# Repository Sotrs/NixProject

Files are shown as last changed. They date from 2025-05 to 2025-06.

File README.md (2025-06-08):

# NixProject By Sotiris Zannetos Readme Work In Progress
Nixe Clock Project Including Electronics, Software and 3d Designing for Enclosure

By looking at the Nixie Datasheet we know that each tube requires 10 different Inputs to turn each digit on (Will not be using the commas). For this clock I will be using the classic IN-14 Tube.


My MCU of choice is the ATmega328P which is a very popular choice that is also used in Arduino devices, it has a very well established documentation and support and can also be programmed using the Arduino IDE. This is exactly what I need as the Arduino IDE by itself is simple and easy to use and is also very well documented and supported by its community.




Now in order to turn on the tubes we need a driver that can take the digital output of the ATmega and turn on the particular digit we want to light up. We have a few problems we must solve in order to achieve that:
1. The clock we want to create will be a Six-Digit clock "HH:MM:SS" meaning we need 60 individual outputs. Unfortunately the Atmega328P can maxes out at '18', including the analog outputs as digital I/O's.
2. The tubes require a whopping 170V DC in order to light up and about 145V DC to keep running. That is not something we can control using only the digital outputs of a 5V DC Microcontroller.

To solve the first problem we can simply use dedicated Drivers, in fact a BCD-TO-DECIMAL Decoder was made specifically for driving Nixie Tubes known as the **SN74141** or its Soviet Sibling the **K155ID1**. This automatically solves the second problem as well as these drivers were created to handle the high voltage. The use of such drivers makes our project very simple as we can use 1 driver for each tube which brings us down from 60 individual outputs to 24 with each driver requiring 4 bits of info to control the 10 digits.



However, the problem is yet to be solved as 24 outputs are still more than what our MCU can give, we can tackle this problem using an I/O Expander with a Serial Interface. Utilizing THE I^2C Interface of the ATmega we can use I/O Expanders such as the **MCP23017** that will give us 16 extra I/O which are now more than enough of what we need. With that we can sucessfuly drive our nixie tubes using the MCU's Outputs!



We are still missing two critical components in our clock, while the ATmega328P can use its Internal 8MHz crystal Oscillator or an external 16MHz one they are still not very good at time keeping as this is not their intended use, also it will be unable to keep time while it is not powered. This is why we will use an RTC which is a device made for timekeeping. My choice of RTC is the **DS3231** with a simple I2C connection and a cr2032 battery it can keep time with an insane 2PPM accuracy.



Last but definetely not least we will need a DC-DC boost converter, the clock will be powered by 5V DC so we will need to take that 5V and convert it to 170V DC for our tubes. An easy solution to this is to use a premade module made by OMNIXIE called the **NCH8200HV**. It is small, efficient and widely used by many nixie clock creators, it simply does its job. It is the only premade module used in this project, dont't worry it will be embedded in our PCB very neatly and discreetly along with the other components.



Now, we have all of our components:
1. MCU -> ATmega 328p-AU
2. Tubes -> IN-14 Gazotron
3. RTC -> DS3231
4. I/O Expander -> MCP 23017  
5. DC-DC Converter -> NCH8200HV
6. SN74141 Drivers -> SN74141/K155ID1

We are ready to start the Electronic architecture, I will be using KiCad to create the schematics and PCB design, an open source and intuitive Electronic design software. Two push buttons will be used to control and set the time by the user. Also in order to program the arduino using the type C interface we will need an external USB to Serial device or in this case we will integrade an FTDI chip directily into our board using the very popular FT232RL.  



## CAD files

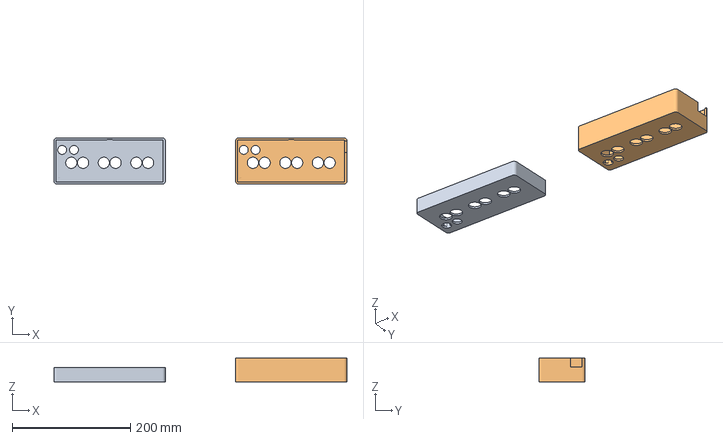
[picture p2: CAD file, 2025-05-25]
Hardware/3d Enclosure/NixieBaseRefined 3d Prinitng.3mf
495.7 x 78.5 x 40.0 mm
Nixie Case higher w holes version v6.step
ABOMINATUS Nixie.step

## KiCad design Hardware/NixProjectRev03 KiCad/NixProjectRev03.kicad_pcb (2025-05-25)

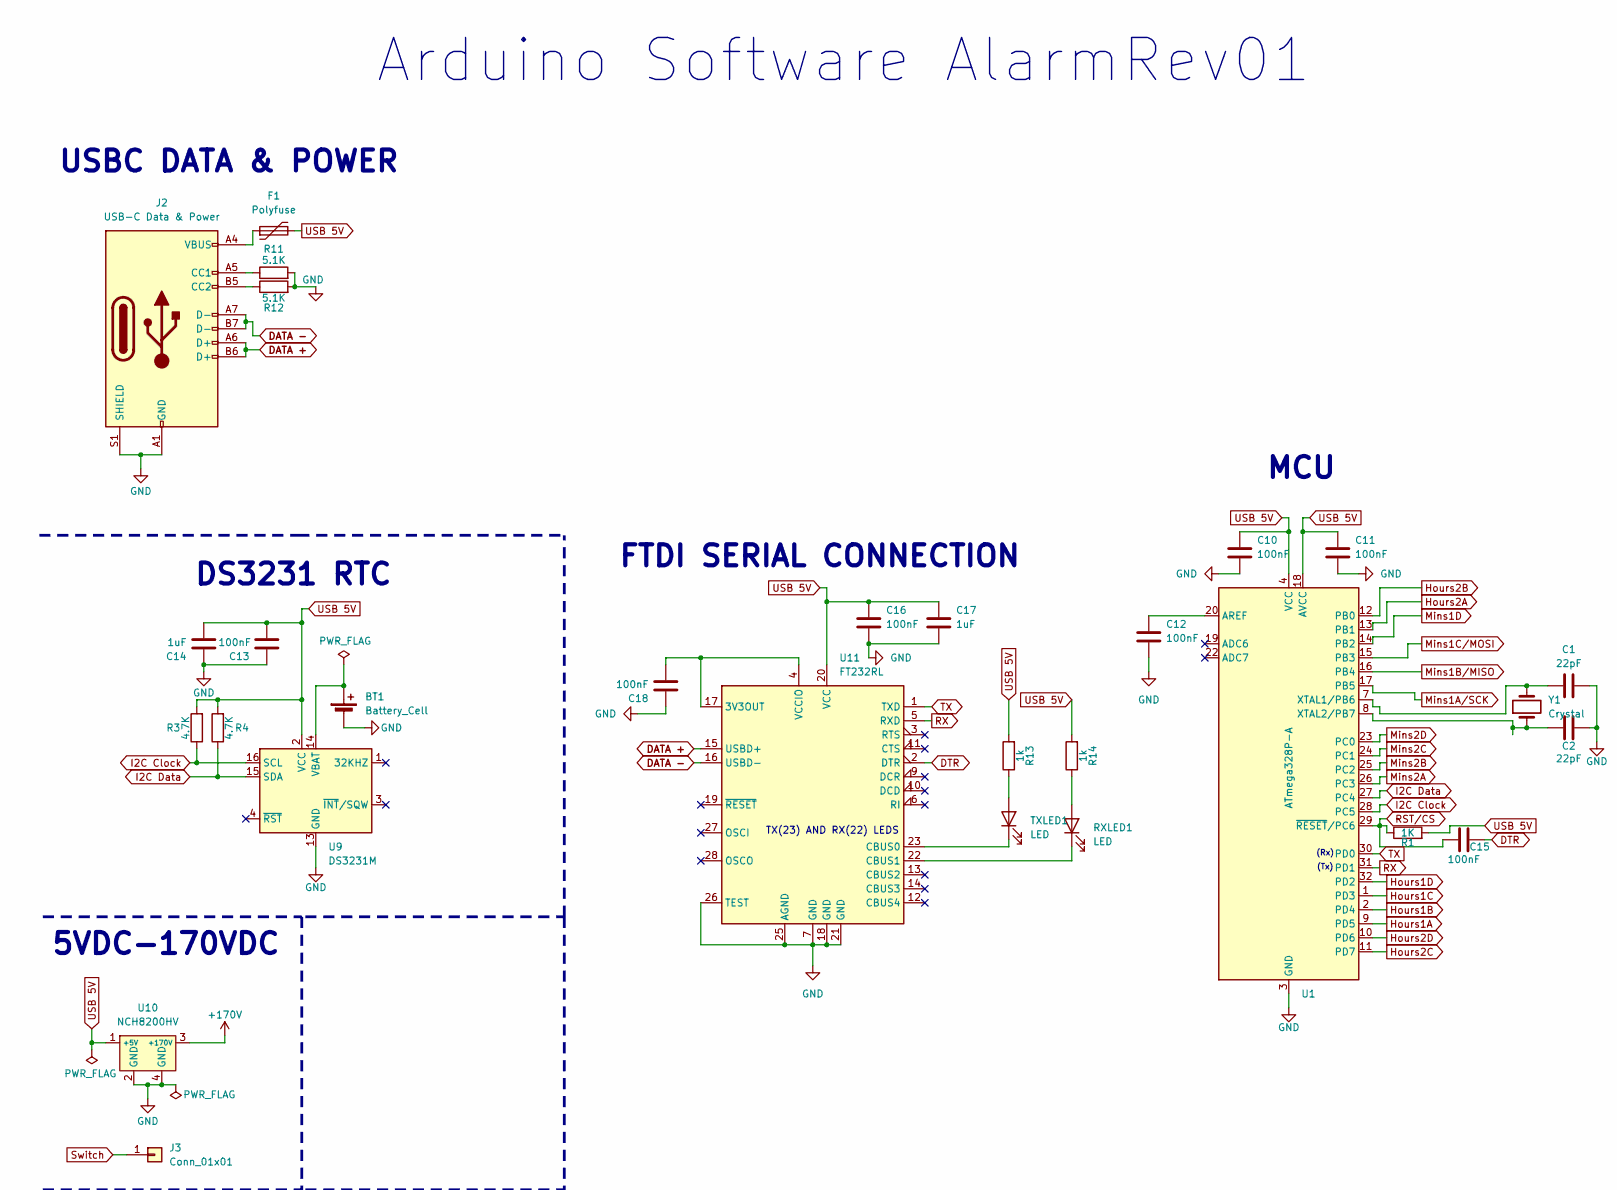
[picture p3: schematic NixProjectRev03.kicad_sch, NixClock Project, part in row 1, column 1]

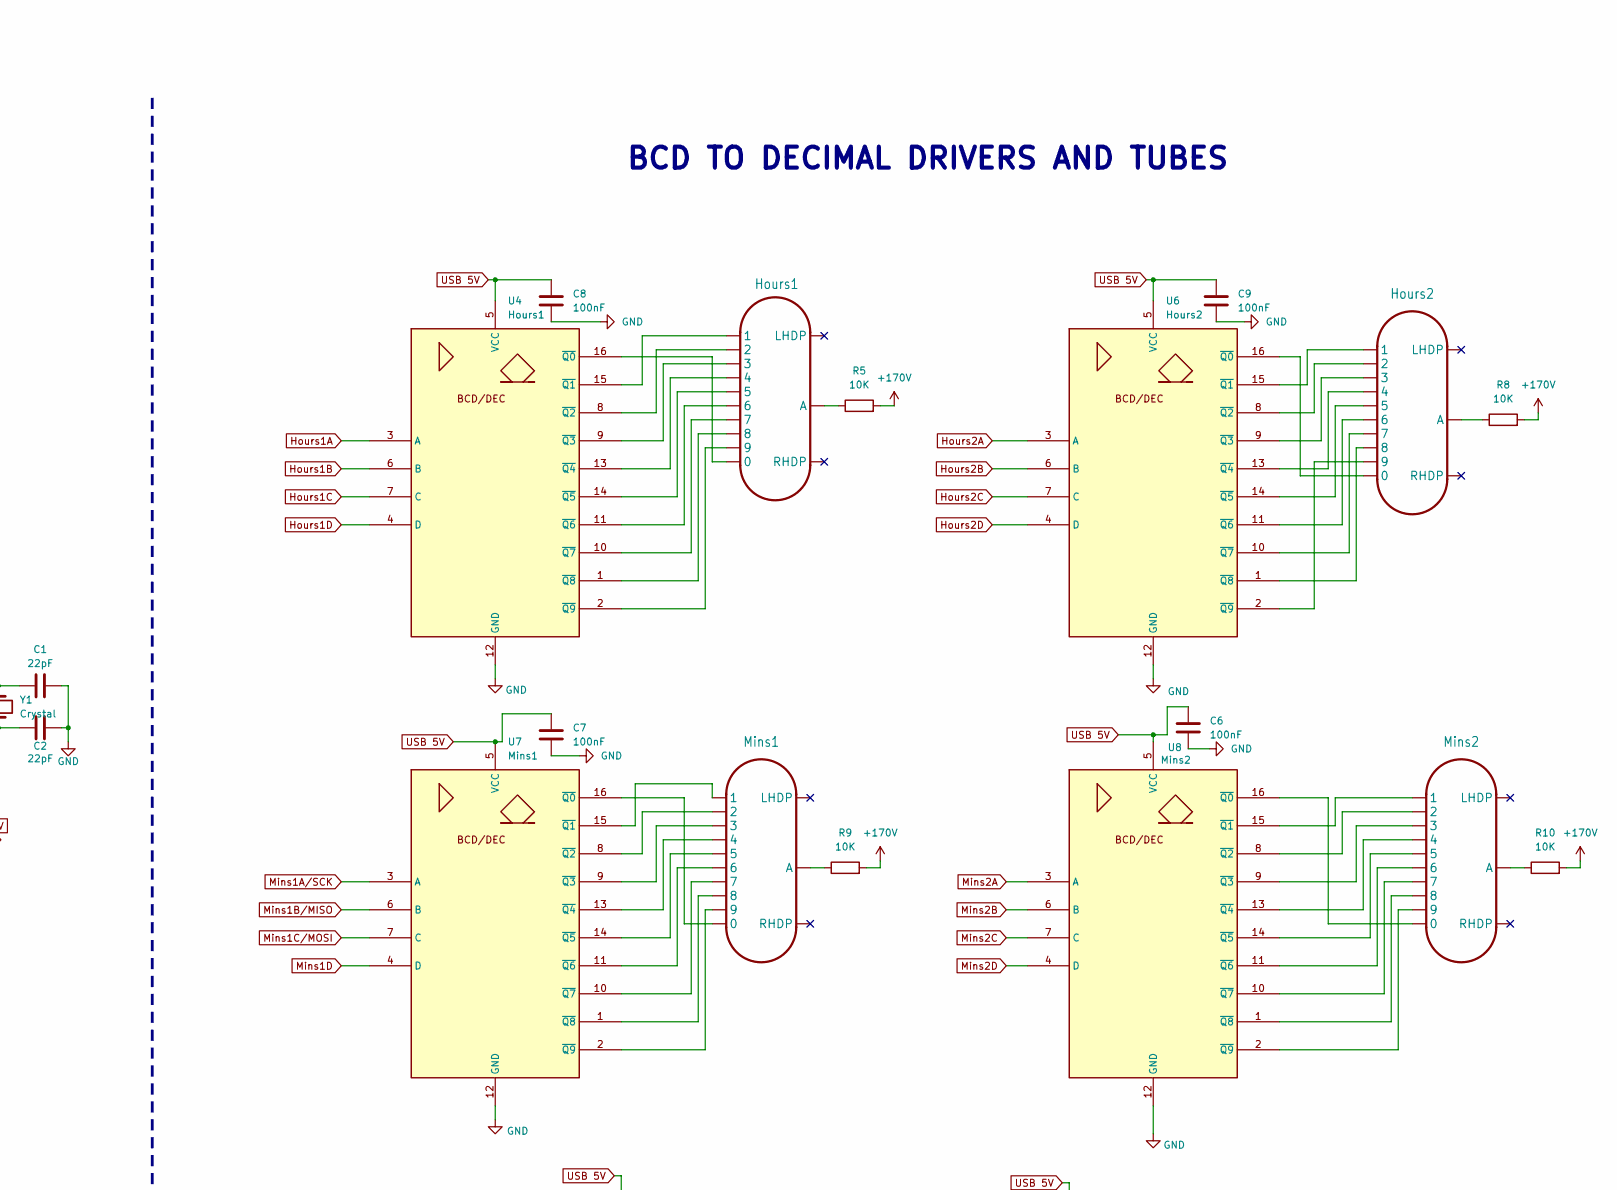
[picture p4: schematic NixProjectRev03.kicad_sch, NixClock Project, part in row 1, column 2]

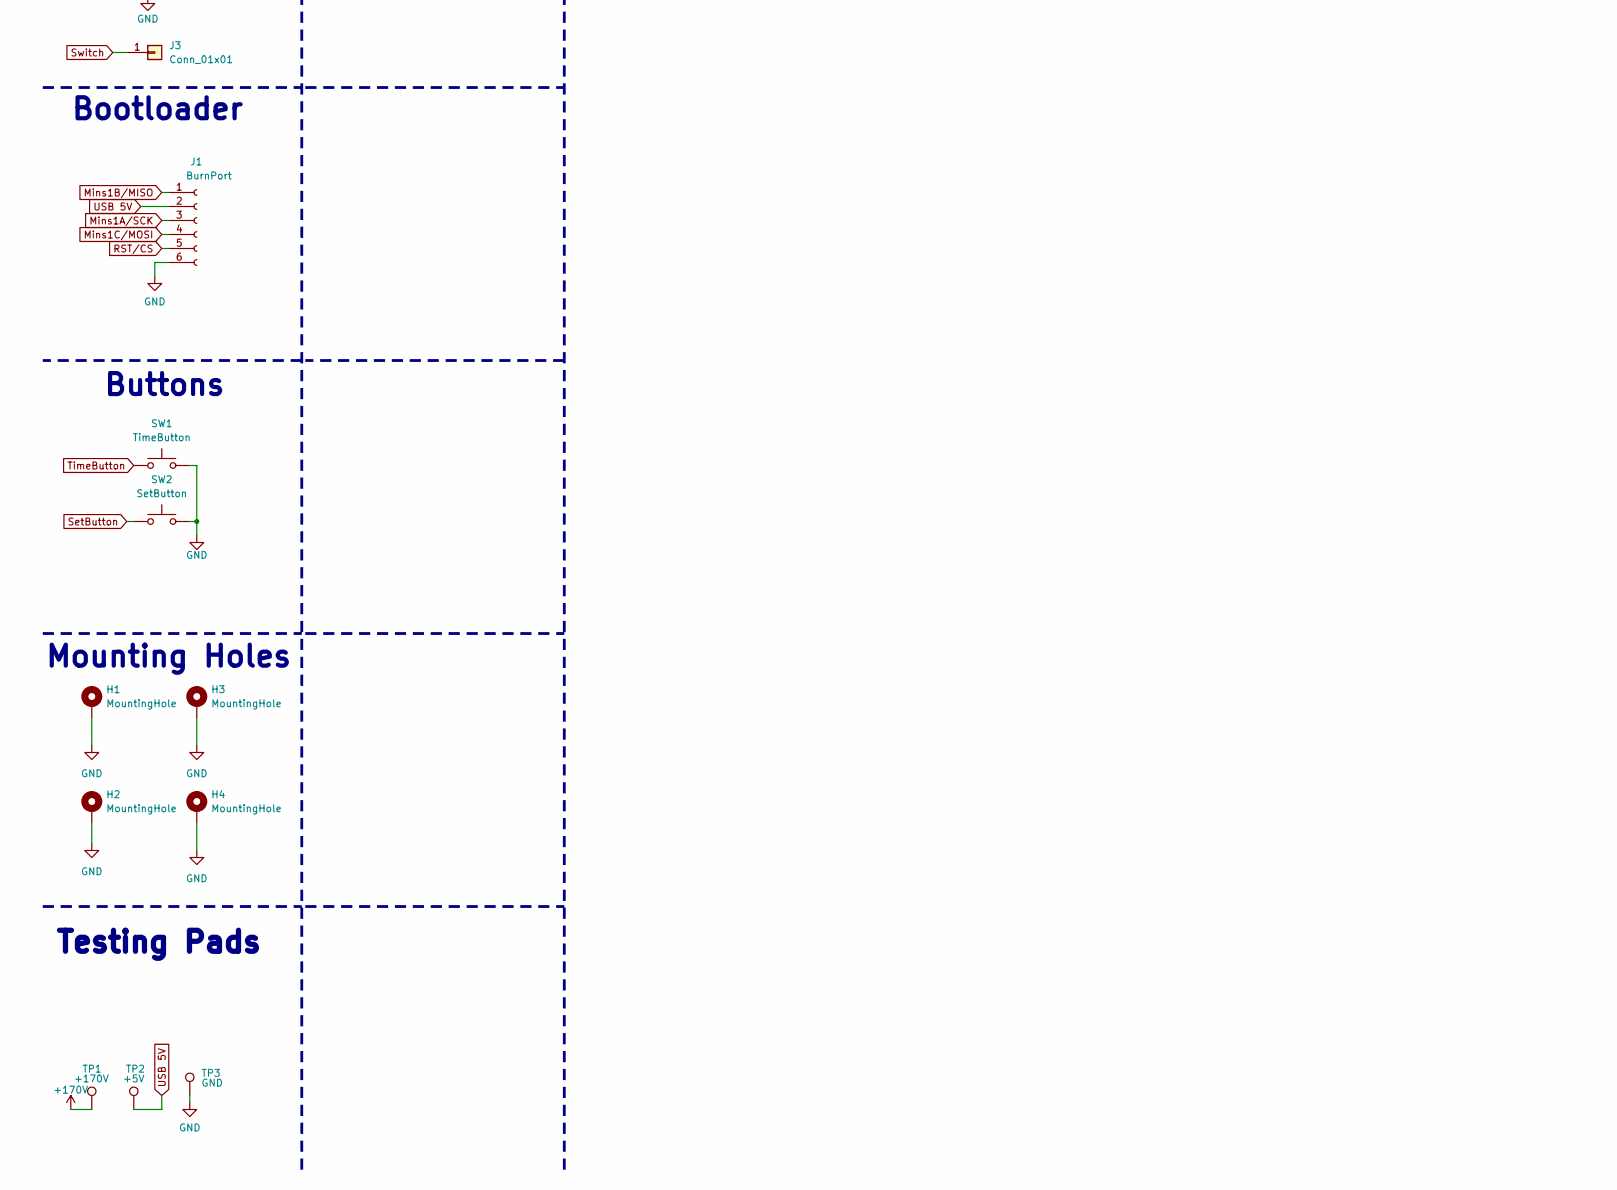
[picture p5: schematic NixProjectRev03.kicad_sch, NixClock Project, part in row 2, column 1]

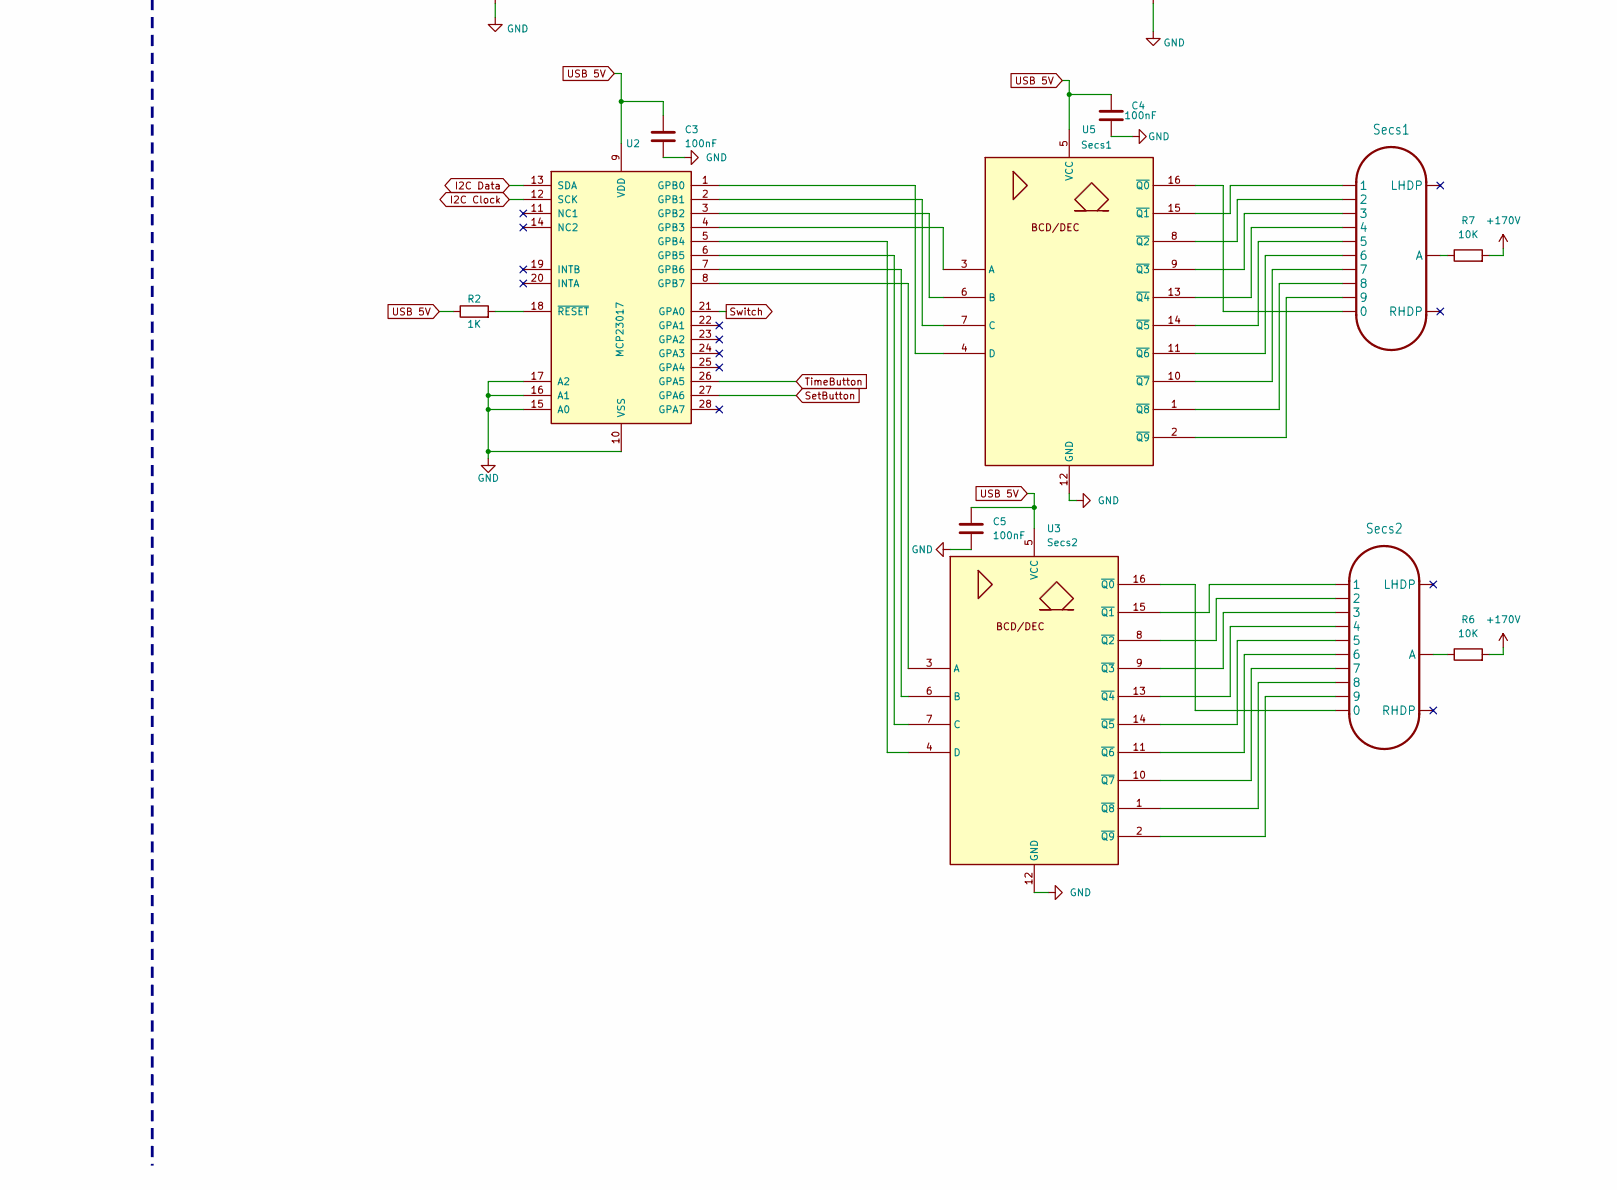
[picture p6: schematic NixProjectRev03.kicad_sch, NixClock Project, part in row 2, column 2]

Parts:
BT1: Battery_Cell; Battery Holder SMD CR2032
C1, C2: 22pF; C_1206_3216Metric_Pad1.33x1.80mm_HandSolder
C3, C4, C5, C6, C7, C8, C9, C10, C11, C12, C13, C15, C16, C18: 100nF; C_1206_3216Metric_Pad1.33x1.80mm_HandSolder
C14, C17: 1uF; C_1206_3216Metric_Pad1.33x1.80mm_HandSolder
F1: Polyfuse; Fuse_1206_3216Metric
H1, H2, H3, H4: MountingHole; MountingHole_4.3mm_M4_DIN965_Pad
Hours1, Hours2: nixies-us-IN-14
J1: BurnPort; PinHeader_2x03_P2.54mm_Vertical
J2: USB-C Data & Power; USB_C_Receptacle_GCT_USB4105-xx-A_16P_TopMnt_Horizontal
J3: Conn_01x01; SolderWire-0.1sqmm_1x01_D0.4mm_OD1mm
Mins1, Mins2: nixies-us-IN-14
R1, R2: 1K; R_0805_2012Metric_Pad1.20x1.40mm_HandSolder
R3, R4: 4.7K; R_0805_2012Metric_Pad1.20x1.40mm_HandSolder
R5, R6, R7, R8, R9, R10: 10K; R_Axial_DIN0204_L3.6mm_D1.6mm_P7.62mm_Horizontal
R11, R12: 5.1K; R_0805_2012Metric_Pad1.20x1.40mm_HandSolder
R13, R14: 1k; R_1206_3216Metric_Pad1.30x1.75mm_HandSolder
RXLED1: LED; LED_1206_3216Metric_Pad1.42x1.75mm_HandSolder
SW1: TimeButton; SW_PUSH-12mm
SW2: SetButton; SW_PUSH-12mm
Secs1, Secs2: nixies-us-IN-14
TP1: +170V; TestPoint_Pad_D2.0mm
TP2: +5V; TestPoint_Pad_D2.0mm
TP3: GND; TestPoint_Pad_D2.0mm
TXLED1: LED; LED_1206_3216Metric_Pad1.42x1.75mm_HandSolder
U1: ATmega328P-A; TQFP-32_7x7mm_P0.8mm
U2: MCP23017; SOIC-28W_7.5x18.7mm_P1.27mm
U3: Secs2; DIP-16_W7.62mm
U4: Hours1; DIP-16_W7.62mm
U5: Secs1; DIP-16_W7.62mm
U6: Hours2; DIP-16_W7.62mm
U7: Mins1; DIP-16_W7.62mm
U8: Mins2; DIP-16_W7.62mm
U9: DS3231M; SOIC-16W_7.5x10.3mm_P1.27mm
U10: NCH8200HV
U11: FT232RL; SSOP-28_5.3x10.2mm_P0.65mm
Y1: Crystal; Crystal_SMD

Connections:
+170V: R5.2, R6.2, R7.2, R8.2, R9.2, R10.2, TP1.1, U10.3 (+170V)
DATA +: J2.A6 (D+), J2.B6 (D+), U11.15 (USBD+)
DATA -: J2.A7 (D-), J2.B7 (D-), U11.16 (USBD-)
DTR: C15.2, U11.2 (DTR)
GND: BT1.2 (-), C1.2, C2.2, C3.1, C4.1, C5.2, C6.2, C7.2, C8.2, C9.2, C10.2, C11.2, C12.2, C13.1, C14.1, C16.2, C17.2, C18.1, H1.1, H2.1, H3.1, H4.1, J1.6, J2.A1 (GND), J2.A12 (GND), J2.B1 (GND), J2.B12 (GND), J2.S1 (SHIELD), R11.2, R12.2, SW1.2, SW2.2, TP3.1, U1.3 (GND), U1.5 (GND), U1.21 (GND), U2.10 (VSS), U2.15 (A0), U2.16 (A1), U2.17 (A2), U3.12 (GND), U4.12 (GND), U5.12 (GND), U6.12 (GND), U7.12 (GND), U8.12 (GND), U9.5 (GND), U9.6 (GND), U9.7 (GND), U9.8 (GND), U9.9 (GND), U9.10 (GND), U9.11 (GND), U9.12 (GND), U9.13 (GND), U10.2 (GND), U10.4 (GND), U11.7 (GND), U11.18 (GND), U11.21 (GND), U11.25 (AGND), U11.26 (TEST)
Hours1A: U1.9 (PD5), U4.3 (A)
Hours1B: U1.2 (PD4), U4.6 (B)
Hours1C: U1.1 (PD3), U4.7 (C)
Hours1D: U1.32 (PD2), U4.4 (D)
Hours2A: U1.13 (PB1), U6.3 (A)
Hours2B: U1.12 (PB0), U6.6 (B)
Hours2C: U1.11 (PD7), U6.7 (C)
Hours2D: U1.10 (PD6), U6.4 (D)
I2C Clock: R3.1, U1.28 (PC5), U2.12 (SCK), U9.16 (SCL)
I2C Data: R4.1, U1.27 (PC4), U2.13 (SDA), U9.15 (SDA)
Mins1A/SCK: J1.3, U1.17 (PB5), U7.3 (A)
Mins1B/MISO: J1.1, U1.16 (PB4), U7.6 (B)
Mins1C/MOSI: J1.4, U1.15 (PB3), U7.7 (C)
Mins1D: U1.14 (PB2), U7.4 (D)
Mins2A: U1.26 (PC3), U8.3 (A)
Mins2B: U1.25 (PC2), U8.6 (B)
Mins2C: U1.24 (PC1), U8.7 (C)
Mins2D: U1.23 (PC0), U8.4 (D)
unnamed: BT1.1 (+), U9.14 (VBAT)
unnamed: F1.1, J2.A4 (VBUS), J2.A9 (VBUS), J2.B4 (VBUS), J2.B9 (VBUS)
unnamed: Hours1.A, R5.1
unnamed: Hours2.A, R8.1
unnamed: J2.A5 (CC1), R11.1
unnamed: J2.B5 (CC2), R12.1
unnamed: Mins1.A, R9.1
unnamed: Mins2.A, R10.1
unnamed: R6.1, Secs2.A
unnamed: R7.1, Secs1.A
unnamed: R14.1, RXLED1.2 (A)
unnamed: RXLED1.1 (K), U11.22 (CBUS1)
unnamed: R13.1, TXLED1.2 (A)
unnamed: TXLED1.1 (K), U11.23 (CBUS0)
unnamed: C12.1, U1.20 (AREF)
unnamed: C1.1, U1.7 (XTAL1/PB6), Y1.2
unnamed: C2.1, U1.8 (XTAL2/PB7), Y1.1
unnamed: U2.1 (GPB0), U5.4 (D)
unnamed: U2.2 (GPB1), U5.7 (C)
unnamed: U2.3 (GPB2), U5.6 (B)
unnamed: U2.4 (GPB3), U5.3 (A)
unnamed: U2.5 (GPB4), U3.4 (D)
unnamed: U2.6 (GPB5), U3.7 (C)
unnamed: U2.7 (GPB6), U3.6 (B)
unnamed: U2.8 (GPB7), U3.3 (A)
unnamed: R2.2, U2.18 (~RESET)
unnamed: Secs2.0, U3.16 (~Q0)
unnamed: Secs2.1, U3.15 (~Q1)
unnamed: Secs2.2, U3.8 (~Q2)
unnamed: Secs2.3, U3.9 (~Q3)
unnamed: Secs2.4, U3.13 (~Q4)
unnamed: Secs2.5, U3.14 (~Q5)
unnamed: Secs2.6, U3.11 (~Q6)
unnamed: Secs2.7, U3.10 (~Q7)
unnamed: Secs2.8, U3.1 (~Q8)
unnamed: Secs2.9, U3.2 (~Q9)
unnamed: Hours1.0, U4.16 (~Q0)
unnamed: Hours1.1, U4.15 (~Q1)
unnamed: Hours1.2, U4.8 (~Q2)
unnamed: Hours1.3, U4.9 (~Q3)
unnamed: Hours1.4, U4.13 (~Q4)
unnamed: Hours1.5, U4.14 (~Q5)
unnamed: Hours1.6, U4.11 (~Q6)
unnamed: Hours1.7, U4.10 (~Q7)
unnamed: Hours1.8, U4.1 (~Q8)
unnamed: Hours1.9, U4.2 (~Q9)
unnamed: Secs1.0, U5.16 (~Q0)
unnamed: Secs1.1, U5.15 (~Q1)
unnamed: Secs1.2, U5.8 (~Q2)
unnamed: Secs1.3, U5.9 (~Q3)
unnamed: Secs1.4, U5.13 (~Q4)
unnamed: Secs1.5, U5.14 (~Q5)
unnamed: Secs1.6, U5.11 (~Q6)
unnamed: Secs1.7, U5.10 (~Q7)
unnamed: Secs1.8, U5.1 (~Q8)
unnamed: Secs1.9, U5.2 (~Q9)
unnamed: Hours2.0, U6.16 (~Q0)
unnamed: Hours2.1, U6.15 (~Q1)
unnamed: Hours2.2, U6.8 (~Q2)
unnamed: Hours2.3, U6.9 (~Q3)
unnamed: Hours2.4, U6.13 (~Q4)
unnamed: Hours2.5, U6.14 (~Q5)
unnamed: Hours2.6, U6.11 (~Q6)
unnamed: Hours2.7, U6.10 (~Q7)
unnamed: Hours2.8, U6.1 (~Q8)
unnamed: Hours2.9, U6.2 (~Q9)
unnamed: Mins1.0, U7.16 (~Q0)
unnamed: Mins1.1, U7.15 (~Q1)
unnamed: Mins1.2, U7.8 (~Q2)
unnamed: Mins1.3, U7.9 (~Q3)
unnamed: Mins1.4, U7.13 (~Q4)
unnamed: Mins1.5, U7.14 (~Q5)
unnamed: Mins1.6, U7.11 (~Q6)
unnamed: Mins1.7, U7.10 (~Q7)
unnamed: Mins1.8, U7.1 (~Q8)
unnamed: Mins1.9, U7.2 (~Q9)
unnamed: Mins2.0, U8.16 (~Q0)
unnamed: Mins2.1, U8.15 (~Q1)
unnamed: Mins2.2, U8.8 (~Q2)
unnamed: Mins2.3, U8.9 (~Q3)
unnamed: Mins2.4, U8.13 (~Q4)
unnamed: Mins2.5, U8.14 (~Q5)
unnamed: Mins2.6, U8.11 (~Q6)
unnamed: Mins2.7, U8.10 (~Q7)
unnamed: Mins2.8, U8.1 (~Q8)
unnamed: Mins2.9, U8.2 (~Q9)
unnamed: C18.2, U11.4 (VCCIO), U11.17 (3V3OUT)
RST/CS: C15.1, J1.5, R1.1, U1.29 (~RESET/PC6)
RX: U1.31 (PD1), U11.5 (RXD)
SetButton: SW2.1, U2.27 (GPA6)
Switch: J3.1, U2.21 (GPA0)
TX: U1.30 (PD0), U11.1 (TXD)
TimeButton: SW1.1, U2.26 (GPA5)
USB 5V: C3.2, C4.2, C5.1, C6.1, C7.1, C8.1, C9.1, C10.1, C11.1, C13.2, C14.2, C16.1, C17.1, F1.2, J1.2, R1.2, R2.1, R3.2, R4.2, R13.2, R14.2, TP2.1, U1.4 (VCC), U1.6 (VCC), U1.18 (AVCC), U2.9 (VDD), U3.5 (VCC), U4.5 (VCC), U5.5 (VCC), U6.5 (VCC), U7.5 (VCC), U8.5 (VCC), U9.2 (VCC), U10.1 (+5V), U11.20 (VCC)

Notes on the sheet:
DS3231 RTC
FTDI SERIAL CONNECTION
(Rx)
5VDC-170VDC
USBC DATA & POWER
(Tx)
Arduino Software AlarmRev01
BCD TO DECIMAL DRIVERS AND TUBES
TX(23) AND RX(22) LEDS
Buttons
Testing Pads
Bootloader
MCU
Mounting Holes

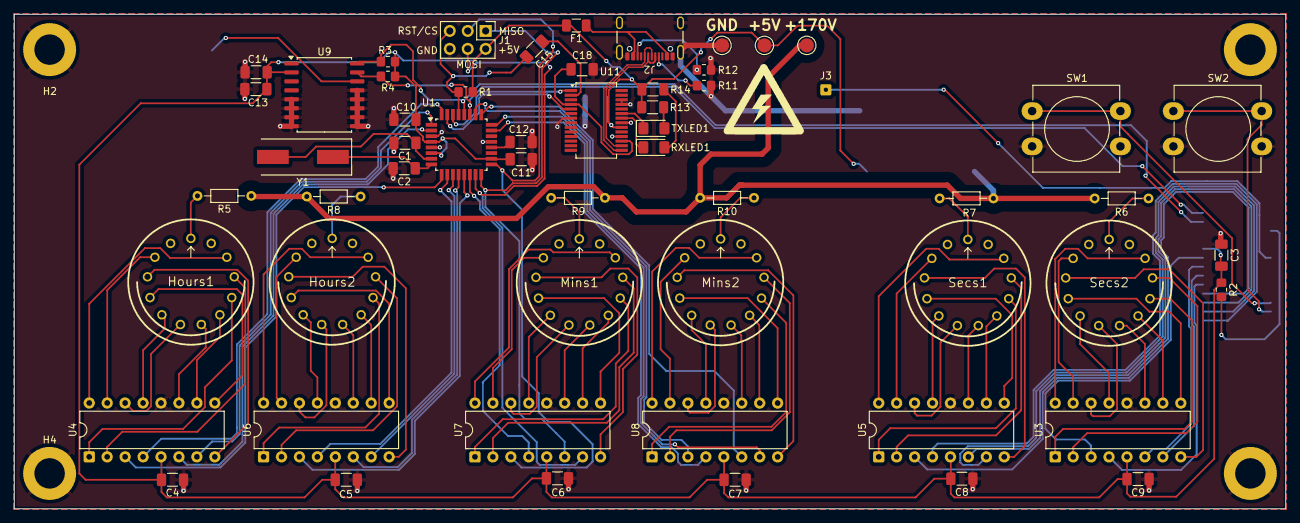
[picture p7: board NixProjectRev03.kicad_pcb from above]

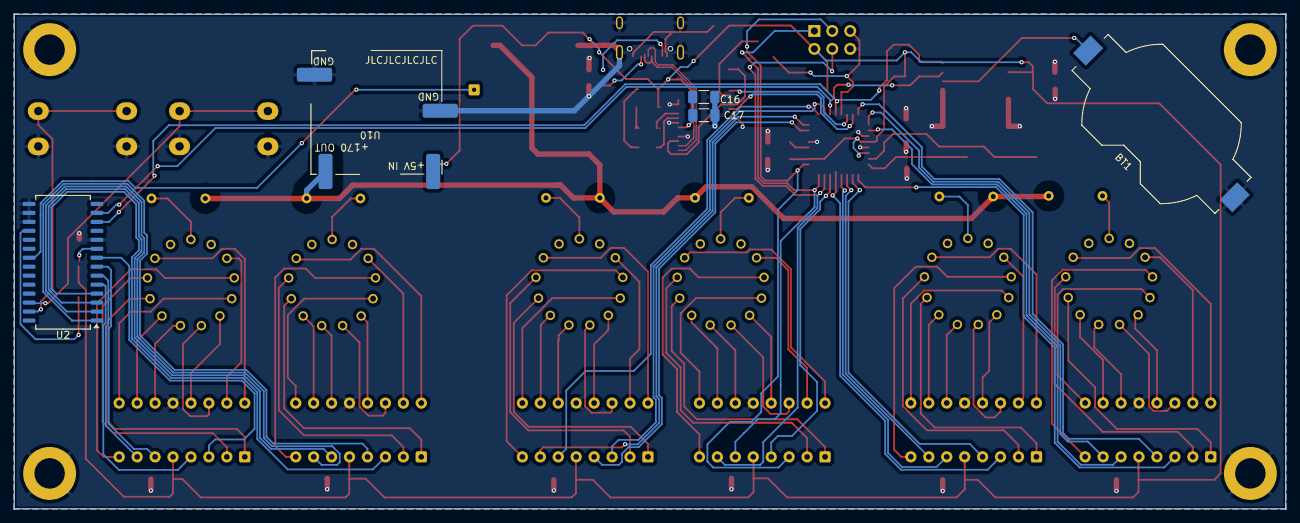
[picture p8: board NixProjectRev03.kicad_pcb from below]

Board: 2 copper layers, 180.0 x 70.0 mm, 66 parts (5 on the bottom side), 117 nets.

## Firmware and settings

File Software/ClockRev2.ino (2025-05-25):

#include <DS3231.h>

#include <Adafruit_MCP23X17.h>
#include <DS3231.h> // by Andrew Wickert
#include <Wire.h>

//COM 8 Is the desktop nixie
// IMPORTANT DURING ACTUAL IMPLEMENTATION THE FIRST BIT 
// THE MOST RIGHT BIT SHOULD BE CONNECTED TO THE LAST OUTPUT OF EACH DIGIT
//!!!! ONE THE DECODER 7441 THE FIRST BIT IS INPUT A
// HOURS1 THE FIRST BIT IS OUT5->INPUT A
// HOURS2 THE FIRST BIT IS OUT9->INPUT A
// MINS1 THE FIRST BIT IS OUT13->INPUT A
// MINS2 THE FIRST BIT IS OUT17 BUT I MAY CHANGE IT TO IMPLIMENT OUTPUT EXTENDER FOR SECONDS
// SECS1 THE FIRST BIT IS IDK BECAUSE I WILL IMPLIMENT OUTPUT EXTENDER
// SAME FOR SECS2

Adafruit_MCP23X17 mcp;
const int Hours1[4] = {2,3,4,5};  // First digit ABCD INPUTS IN DECODER, IN REALITY IT IS DCBA(Binary starting from the right) AS IT IS WRITTEN IN THE ARRAY
const int Hours2[4] = {6,7,8,9};  // Second Digit
const int Mins1[4] = {10,11,12,13}; // Third Digit
const int Mins2[4] = {14,15,16,17}; // Fourth Digit
const int Secs1[4] = {8,9,10,11}; //MCP PINS 8,9,10,11
const int Secs2[4] = {12,13,14,15}; //MCP PINS 12,13,14,15

byte Hours; //will hold the decimal value of time for the RTC communication
byte Minutes;
byte Seconds;
DS3231 myRTC; //rtc object 

bool century = false;
bool h12 = false;
bool hPM;

int CurrentMode = 0; //0 PRINT TIME(Running Mode), 1 SET TIME, 2 DIGIT INTEGRITY TESTING, 3 Number Animation/Cathode cure, 4 EXPERIMENTAL TESTING <-------------------------------------------------------------------
bool SetScreenFlag = true;

int TimeButton = 5; //Set time button D2->2 | ON MCP TimeButton is Pin 5(Physical 26)
int ButtonState;
int TimeButtonCount = -1;
int LastButtonState = LOW;
unsigned long LastDebounceTime = 0;  // the last time the output pin was toggled
unsigned long DebounceDelay = 50;    // In milliseconds the debounce time | increase if the output flickers 


int SetButton = 6 ;//Set Button D3->3 | ON MCP IT SetButton is Pin 6(Physical 27)
int SetButtonState;
int SetButtonCount = 0;
int LastSetButtonState = LOW;
unsigned long LastSetDebounceTime = 0;

byte BCD[10][4] = { // D,C,B,A Binary written as in theory for easier understanding
  {0,0,0,0}, //binary 0
  {0,0,0,1}, //1
  {0,0,1,0}, //2
  {0,0,1,1}, //3
  {0,1,0,0}, //4
  {0,1,0,1}, //5
  {0,1,1,0}, //6
  {0,1,1,1}, //7
  {1,0,0,0}, //8
  {1,0,0,1} //9
};

byte DIM[1][4] ={ {1,1,1,1} }; // Over limit number 15

void CathodeCure(){ //==========================================================Cathode Curing Function===========================================================================
  uint8_t digits1[]={0,1,2,3,4,5,6,7,8,9}; // One array for each DECIMAL digit
  uint8_t digits2[]={0,1,2,3,4,5,6,7,8,9}; //As each digit will display a different randomised number
  uint8_t digits3[]={0,1,2,3,4,5,6,7,8,9}; //This means 6 different picks,
  uint8_t digits4[]={0,1,2,3,4,5,6,7,8,9};
  uint8_t digits5[]={0,1,2,3,4,5,6,7,8,9};
  uint8_t digits6[]={0,1,2,3,4,5,6,7,8,9}; //last pick
  uint8_t array_size = sizeof(digits1) / sizeof(digits1[0]); //initial array size, all get reduced equally

  while(array_size){ //while array exists(has at least one input)
    TimeButtonRead(TimeButton); //Keep reading input while clock is running
    uint8_t pick1 = random(0, array_size);
    uint8_t pick2 = random(0, array_size);
    uint8_t pick3 = random(0, array_size);
    uint8_t pick4 = random(0, array_size);
    uint8_t pick5 = random(0, array_size);
    uint8_t pick6 = random(0, array_size);
    int currentDigit1 = digits1[pick1];
    int currentDigit2 = digits2[pick2]; 
    int currentDigit3 = digits3[pick3];
    int currentDigit4 = digits4[pick4];
    int currentDigit5 = digits5[pick5];
    int currentDigit6 = digits6[pick6];
    
    Serial.print(currentDigit1);
    Serial.print("  ");
    Serial.print(currentDigit2);
    Serial.print("  ");
    Serial.print(currentDigit3);
    Serial.print("  ");
    Serial.print(currentDigit4);
    Serial.print("  ");
    Serial.print(currentDigit5);
    Serial.print("  ");
    Serial.println(currentDigit6);
    
    for(int i = 0; i<4; i++){
      digitalWrite(Hours1[i],BCD[currentDigit1][i]);
      digitalWrite(Hours2[i],BCD[currentDigit2][i]);
      digitalWrite(Mins1[i],BCD[currentDigit3][i]);
      digitalWrite(Mins2[i],BCD[currentDigit4][i]);
      mcp.digitalWrite(Secs1[i],BCD[currentDigit5][i]);
      mcp.digitalWrite(Secs2[i],BCD[currentDigit6][i]);
    }

  delay(500); //Change this delay to increase or decrease the appear time of each digit
  
  digits1[pick1] = digits1[array_size - 1]; // The last digit takes the currents numbers position before it is erased
  digits2[pick2] = digits2[array_size - 1];
  digits3[pick3] = digits3[array_size - 1];
  digits4[pick4] = digits4[array_size - 1];
  digits5[pick5] = digits5[array_size - 1];
  digits6[pick6] = digits6[array_size - 1];
  array_size--; //Reduce the array by erasing the last digit
  }

 Serial.println("----------------------------------"); 
}

void TimeButtonRead(int Button){ //=================================================TimeButtonRead Reading Function=========================================================
  int reading = mcp.digitalRead(Button);
  
  if(reading != LastButtonState){ //Gets the input from pressing or noise
    LastDebounceTime = millis();   //Resets the Debouncing timer
  }

  if ((millis() - LastDebounceTime) > DebounceDelay) { //If that time is longer than our Preset "Real button press" delay
                                                        // Then it must be a true button press
    if (reading != ButtonState) {
      ButtonState = reading;
      if(ButtonState == LOW){ //Button Pressed Succesfully Do things HERE   
        CurrentMode=1; //Time setting mode
        TimeButtonCount++; //Time button count is the actual number the user wants by each press you increase it which is also the digit on the clock.
        if(SetButtonCount==4){ //In combination with SetDigit() when counting seconds pressing the button you only reset them to 0
          myRTC.setSecond(0);  // reset seconds to 0 on button press
        }
        //Serial.println (TimeButtonCount);
      } //Button is pressed
    } //REAL Button Press
  }
  LastButtonState = reading;
}

void SetButtonRead(int Button){ //=================================================SetButtonRead Reading Function=========================================================
  int reading = mcp.digitalRead(Button);
  
  if(reading != LastSetButtonState){ //Gets the input from pressing or noise
    LastSetDebounceTime = millis();   //Resets the Debouncing timer
  }

  if ((millis() - LastSetDebounceTime) > DebounceDelay) { //If that time is longer than our Preset "Real button press" delay
                                                        // Then it must be a true button press
    if (reading != SetButtonState) {
      SetButtonState = reading;
      if(SetButtonState == LOW){ //Button Pressed Succesfully Do things HERE   ;
        SetButtonCount++;
        //Serial.println (SetButtonCount);
      }//Button is pressed
    }//REAL Button Press
  } 
  LastSetButtonState = reading;
}

void SetDigit(){ //================================================================== SET DIGIT ===================================================================================
      while (SetButtonCount == 0){ //Set Hour1 Digit Hour one has 0,1,2 No Other digits
        //BlinkDots();
        TimeButtonRead(TimeButton);
        SetButtonRead(SetButton);
        if(TimeButtonCount>2){ //timebutton count will keep track of 0,1,2 digits
          TimeButtonCount = 0;
        }
        Serial.println (TimeButtonCount);
        for(int i = 0; i<4; i++){ //This now writes the same time to all DIGITS, we can use the second button to differentiate them
          digitalWrite(Hours1[i],BCD[TimeButtonCount][i]);
        }   
      }
      Hours = TimeButtonCount*10; //First digit is in the 10's After set button is pressed

      TimeButtonCount= 0; //Reset Time button
      while (SetButtonCount == 1){ //Set Hour2 Digit Hour one has 0,1,2,3,4,5,6,7,8,9 Digits
        //BlinkDots();
        TimeButtonRead(TimeButton);
        SetButtonRead(SetButton);
        if(TimeButtonCount>9){
          TimeButtonCount= 0;
        }
        Serial.println (TimeButtonCount);             
        for(int i = 0; i<4; i++){ //This now writes the same time to all DIGITS, we can use the second button to differentiate them
          digitalWrite(Hours2[i],BCD[TimeButtonCount][i]);
        }   
      }
      Hours += TimeButtonCount;// Second Digit is in the 1's
      myRTC.setHour(Hours); //Set Final Hours

      TimeButtonCount= 0; //Reset Time button
      while (SetButtonCount == 2){ //Set Min1 Digit Hour one has 0,1,2,3,4,5 Digits
        //BlinkDots();
        TimeButtonRead(TimeButton);
        SetButtonRead(SetButton);
        if(TimeButtonCount>5){
          TimeButtonCount= 0;
        }
        Serial.println (TimeButtonCount);
        for(int i = 0; i<4; i++){ //This now writes the same time to all DIGITS, we can use the second button to differentiate them
          digitalWrite(Mins1[i],BCD[TimeButtonCount][i]);
        }   
      }
      Minutes = TimeButtonCount*10; //Multiplying by 10 to place it into the First Digit

      TimeButtonCount = 0; //Reset Time button
      while (SetButtonCount == 3){ //Set Min2 Digit Hour one has 0,1,2,3,4,5,6,7,8,9 Digits
        //BlinkDots();
        TimeButtonRead(TimeButton);
        SetButtonRead(SetButton);
        if(TimeButtonCount>9){
          TimeButtonCount= 0;
        }
        Serial.println (TimeButtonCount);
        for(int i = 0; i<4; i++){ //This now writes the same time to all DIGITS, we can use the second button to differentiate them
          digitalWrite(Mins2[i],BCD[TimeButtonCount][i]);
        }   
      }
      Minutes += TimeButtonCount; //And then adding the second Digit 
      myRTC.setMinute(Minutes);

      while (SetButtonCount == 4){ //Resetting seconds
        //BlinkDots();
        Seconds = myRTC.getSecond();
        TimeButtonRead(TimeButton);
        SetButtonRead(SetButton);
        if(TimeButtonCount>9){
          TimeButtonCount= 0;
        }
        for(int i = 0; i<4; i++){ 
          mcp.digitalWrite(Secs1[i],BCD[Seconds/10][i]);
          mcp.digitalWrite(Secs2[i],BCD[Seconds%10][i]);
        }
        Serial.println (Seconds); //DIGITAL WRITE HERE
      }

      if(SetButtonCount > 4){ //Time Set succesfully So going back to counting time and reseting the SetButton, TimeButton and Current Mode
        CurrentMode = 0; //Count Time Mode
        TimeButtonCount = -1; //Reset Time button
        SetScreenFlag=true; //Will make everything zero at first press
        SetButtonCount = 0; //Reset Set Button
      }

}//SetDigit Function END

void WriteTime(){ //========================================================================= WRITE TIME ================================================================================
    if(myRTC.getMinute() % 30 == 0 && Seconds==0){ //Animation every 10 mins
    for(int i=0;i<6;i++)
      CathodeCure();
  }

  if(((myRTC.getMinute() % 5 == 0)  || (myRTC.getMinute() % 10 == 0)) && Seconds==0){ //Animation every 10 mins
    NumberAnimation();
  }

  Hours = myRTC.getHour(h12, hPM);
  Minutes = myRTC.getMinute();  
  Seconds = myRTC.getSecond();
  for(int i = 0; i<4; i++){
    digitalWrite(Hours1[i],BCD[Hours/10][i]);
    digitalWrite(Hours2[i],BCD[Hours%10][i]);
    digitalWrite(Mins1[i],BCD[Minutes/10][i]);
    digitalWrite(Mins2[i],BCD[Minutes%10][i]);
    mcp.digitalWrite(Secs1[i],BCD[Seconds/10][i]); 
    mcp.digitalWrite(Secs2[i],BCD[Seconds%10][i]);
  }

  /*  //DIMMING EXPERIMENT
    for(int i = 0; i<4; i++){ 
    digitalWrite(Hours1[i],DIM[0][i]);
    digitalWrite(Hours2[i],DIM[0][i]);
    digitalWrite(Mins1[i],DIM[0][i]);
    digitalWrite(Mins2[i],DIM[0][i]);
    mcp.digitalWrite(Secs1[i],DIM[0][i]); 
    mcp.digitalWrite(Secs2[i],DIM[0][i]);
  }*/

}//WriteTime Function END



void NumberAnimation(){ //=============================================================== NUMBER ANIMATION ================================================================================
  uint8_t pick1; //THIS PART IS RETARED AS FUCK BUT WORKS...
  uint8_t pick2;
  uint8_t pick3;
  uint8_t pick4; 
  uint8_t pick5; 
  uint8_t pick6; 
  int AniArr[] = {0,0,0,0,0,0}; //Amount of nuber rolls by a set value
  int del=40; //delay time

  while(AniArr[0]<18){ //ALL digits rolling eg. 18 numbers for the first
    pick1 = random(0,9);
    pick2 = random(0,9);
    pick3 = random(0,9);
    pick4 = random(0,9);
    pick5 = random(0,9);
    pick6 = random(0,9);

    for(int i = 0; i<6; i++){
      digitalWrite(Hours1[i],BCD[pick1][i]);
      digitalWrite(Hours2[i],BCD[pick2][i]);
      digitalWrite(Mins1[i],BCD[pick3][i]);
      digitalWrite(Mins2[i],BCD[pick4][i]);
      mcp.digitalWrite(Secs1[i],BCD[pick5][i]); 
      mcp.digitalWrite(Secs2[i],BCD[pick6][i]);
    }
    delay(del); //Has a bit of delay so it's visible to the eye
    AniArr[0]++; //Amount of rolls by a set time
  }

  while(AniArr[1]<18){ //Hour1 First Digit LOCKED others rolling
    Hours = myRTC.getHour(h12, hPM);
    pick1 = random(0,9);
    pick2 = random(0,9);
    pick3 = random(0,9);
    pick4 = random(0,9);
    pick5 = random(0,9);
    for(int i = 0; i<4; i++){
      digitalWrite(Hours1[i],BCD[Hours/10][i]);
      digitalWrite(Hours2[i],BCD[pick1][i]);
      digitalWrite(Mins1[i],BCD[pick2][i]);
      digitalWrite(Mins2[i],BCD[pick3][i]);
      mcp.digitalWrite(Secs1[i],BCD[pick4][i]); 
      mcp.digitalWrite(Secs2[i],BCD[pick5][i]);
    }
    delay(del); //Has a bit of delay so it's visible to the eye
    AniArr[1]++;
  }

  while(AniArr[2]<18){ //Hour2 Second Digit LOCKED others rolling
    Hours = myRTC.getHour(h12, hPM);
    pick1 = random(0,9);
    pick2 = random(0,9);
    pick3 = random(0,9);
    pick4 = random(0,9);
    for(int i = 0; i<4; i++){
      digitalWrite(Hours2[i],BCD[Hours%10][i]);
      digitalWrite(Mins1[i],BCD[pick1][i]);
      digitalWrite(Mins2[i],BCD[pick2][i]);
      mcp.digitalWrite(Secs1[i],BCD[pick3][i]); 
      mcp.digitalWrite(Secs2[i],BCD[pick4][i]);
    }
    delay(del); //Has a bit of delay so it's visible to the eye
    AniArr[2]++;
  }

  while(AniArr[3]<18){ //Minute1 Third Digit LOCKED others rolling
    Minutes = myRTC.getMinute();  
    pick1 = random(0,9);
    pick2 = random(0,9);
    pick3 = random(0,9);
    for(int i = 0; i<4; i++){
      digitalWrite(Mins1[i],BCD[Minutes/10][i]);
      digitalWrite(Mins2[i],BCD[pick1][i]);
      mcp.digitalWrite(Secs1[i],BCD[pick2][i]); 
      mcp.digitalWrite(Secs2[i],BCD[pick3][i]);
    }
    delay(del); //Has a bit of delay so it's visible to the eye
    AniArr[3]++;
  }

  while(AniArr[4]<18){ //Minute2 Fourth Digit LOCKED others rolling(Not yet, seconds will be rolling)
    Minutes = myRTC.getMinute();  
    pick1 = random(0,9);
    pick2 = random(0,9);
    for(int i = 0; i<4; i++){
      digitalWrite(Mins2[i],BCD[Minutes%10][i]);
      mcp.digitalWrite(Secs1[i],BCD[pick1][i]); 
      mcp.digitalWrite(Secs2[i],BCD[pick2][i]);
    }
    delay(del); //Has a bit of delay so it's visible to the eye
    AniArr[4]++;
  }

    while(AniArr[5]<18){ //Second1 Fifth Digit LOCKED Second2 wont roll FINISHED
    Seconds = myRTC.getSecond();  
    pick1 = random(0,9);
    for(int i = 0; i<4; i++){
      mcp.digitalWrite(Secs1[i],BCD[Seconds/10][i]); 
      mcp.digitalWrite(Secs2[i],BCD[pick1][i]);
    }
    delay(del); //Has a bit of delay so it's visible to the eye
    AniArr[5]++;
  }
}

void PrintDate(){ //========================================================================= PRINT DATE ========================================================================================
  Serial.print (myRTC.getDate(), DEC); //just printing the date in the console
  Serial.print ("(");
  Serial.print (myRTC.getDoW()); //1. Monday - 7. Sunday
  Serial.print (")");
  Serial.print ("/");
  Serial.print (myRTC.getMonth(century), DEC);
  Serial.print ("/");
  Serial.println (myRTC.getYear(), DEC);  
}

void Alarm(){ //========================================================================= ALARM ========================================================================================
  if(myRTC.getDoW() >6){
    if(myRTC.checkIfAlarm(1,false) == 1){ //Checking If alarmflag is raised
     digitalWrite(Sound,0); //Turn on Sound
     digitalWrite(Mosfet,1); //Turn on Tubes
    }
  } 
}

void setup() { //========================================================================= SET UP ========================================================================================
  mcp.begin_I2C(0x20); //Start Mcp OBJECT A0,A1,A2 Pins ALL PULLED TO GND 
  Serial.begin(9600); // make serial monitor match
  Serial.println ("Setup Initiated");
  Serial.print ("Current Mode: ");
  Serial.println (CurrentMode);
  Wire.begin(); //Start I2C Interface
  //myRTC.setClockMode(false);  // set clock to 24H, True for 12H
  startMillis = millis();  //initial start time

  //Set all outputs 
  mcp.pinMode(TimeButton,INPUT_PULLUP); 
  mcp.pinMode(SetButton,INPUT_PULLUP);
  mcp.pinMode(Mosfet,OUTPUT); //MOSFET FOR BLANKING TUBES
  mcp.pinMode(Sound,OUTPUT); //ALARM SOUND CARD Signal
  for(int i=0; i<4; i++){ //Set all outputs for the digits
    pinMode(Hours1[i],OUTPUT);
    pinMode(Hours2[i],OUTPUT);
    pinMode(Mins1[i],OUTPUT);
    pinMode(Mins2[i],OUTPUT);
    mcp.pinMode(Secs1[i],OUTPUT);
    mcp.pinMode(Secs2[i],OUTPUT);
  }  
  digitalWrite(Sound,1); //When sound 0(Low) Alarm will play
  digitalWrite(Mosfet,0); //Tubes are turned off by default(0-Low) When Mosfet is 1 Tubes turn on
  for(int i = 0; i<4; i++){ //Turn all digits to '0'
    digitalWrite(Hours1[i],BCD[0][i]);
    digitalWrite(Hours2[i],BCD[0][i]);
    digitalWrite(Mins1[i],BCD[0][i]);
    digitalWrite(Mins2[i],BCD[0][i]);
    mcp.digitalWrite(Secs1[i],BCD[0][i]);
    mcp.digitalWrite(Secs2[i],BCD[0][i]);
  }
   /*
    myRTC.setYear(25);
    myRTC.setMonth(3);
    myRTC.setDate(16);
    myRTC.setDoW(7); */
} // SETUP END

void loop() { //============================================================================ LOOP ========================================================================================

  switch(CurrentMode){
    case 0: //============================================================================ TIME PRINT MODE =================================================================================
      //calling print time function and serial monitoring
      WriteTime();
      PrintDate();
      TimeButtonRead(TimeButton);
      Serial.print (Hours);
      Serial.print (":");
      Serial.print (Minutes);
      Serial.print (":");
      Serial.println (Seconds);
      
    break;

    case 1: //============================================================================ TIME SET MODE ========================================================================================
      if(SetScreenFlag==true){ //just set the screen ONCE at the first button press
        for(int i = 0; i<4; i++){ //Set Screen 0000
            digitalWrite(Hours1[i],BCD[0][i]);
            digitalWrite(Hours2[i],BCD[0][i]);
            digitalWrite(Mins1[i],BCD[0][i]);
            digitalWrite(Mins2[i],BCD[0][i]);
            mcp.digitalWrite(Secs1[i],BCD[0][i]); 
            mcp.digitalWrite(Secs2[i],BCD[0][i]);
        }
        SetScreenFlag = false;
      }
      SetDigit();
    break;

    case 2: //============================================================================ DIGIT TESTING ========================================================================================
      //Digit Testing
      for(int c=0; c<10; c++){
        for(int i = 0; i<4; i++){ //All digits will turn on for one second
          digitalWrite(Hours1[i],BCD[c][i]);
          digitalWrite(Hours2[i],BCD[c][i]);
          digitalWrite(Mins1[i],BCD[c][i]);
          digitalWrite(Mins2[i],BCD[c][i]);
          mcp.digitalWrite(Secs1[i],BCD[c][i]);
          mcp.digitalWrite(Secs2[i],BCD[c][i]);
        }
        Serial.println(c);
        delay(1000);
      }
    break;

    case 3: //============================================================================ ANIMATIONS ======================================================================================== 
        //CathodeCure();
        NumberAnimation();
    break;

    case 4: //============================================================================ EXPIREMENTAL ========================================================================================
      /* Dimming Testing
      for(int i = 0; i<4; i++){ 
        digitalWrite(Hours1[i],DIM[0][i]);
        digitalWrite(Hours2[i],DIM[0][i]);
        digitalWrite(Mins1[i],DIM[0][i]);
        digitalWrite(Mins2[i],DIM[0][i]);
        mcp.digitalWrite(Secs1[i],DIM[0][i]); 
        mcp.digitalWrite(Secs2[i],DIM[0][i]);
        }
        */
      // Alarm Testing
      //myRTC.checkIfAlarm(1,false);
    break;
  } //SWITCH END
}//MAIN LOOP END

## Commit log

2025-05-25 Renamed Hardware Folder
    [NixProjectRev03-B_Cu.gbl, NixProjectRev03-B_Mask.gbs, NixProjectRev03-B_Paste.gbp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]
2025-05-25 Rename Kicad Folder
    [NixProjectRev03-B_Cu.gbl, NixProjectRev03-B_Mask.gbs, NixProjectRev03-B_Paste.gbp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]
2025-05-25 Add Arduino libs

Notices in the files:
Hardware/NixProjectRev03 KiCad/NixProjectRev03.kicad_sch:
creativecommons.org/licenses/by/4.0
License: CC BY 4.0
